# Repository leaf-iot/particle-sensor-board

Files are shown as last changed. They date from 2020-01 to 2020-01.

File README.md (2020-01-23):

# particle-sensor-board
Particle / Feather based sensor interface board

Interface for Particle Boron/Argon/Xenon and other Feather compliant boards.

Features:
- Input voltage and current monitoring via INA226
- On-board microSD card slot for data logging
- On-board BME280 Sensor for Temp / Humidity / Barometric Pressure
- Two Atlas Scientific EZO sensor interfaces with full isolation
- Two 4-20mA current loop interfaces
- 3.3V, GND, A0, A1, D8 pins exposed on screw terminal block
- DC input is 3.5x1.1mm (meant for Voltaic Systems solar panels)
- Enable / Disable EZO and 4-20mA power via I/O pins from Feather device
- TTL Serial pins exposed via separate 4-pin header

Known Issues:
- There is a bug in the microSD card circuit, the MISO and MOSI lines were reversed accidentally during development. Due to this, software SPI needs to be used with the pins configured this way.
- No on-board battery charging circuit. We relied on the Particle Boron's built in BQ24195 chip for charging, however up to this point we have had nothing but issues with this. There have been several hardware and firmware issues identified by the community with the Boron (including incorrectly limiting charge current when using the VUSB pin, input current limit settings not being honored, as well as several issues with solar charging in sleep mode). Some of these problems are yet to be fixed as of this release. 
- Particle Boron u-blox modems are capable of connecting to Verizon, but Borons produced after a certain date were never registered with Verizon, and as such you will have nothing but problems with connectivity and FPLMN blacklists if you attempt to use these devices with Verizon or Hologram sim cards. Stick with the internal sim and you should be okay.

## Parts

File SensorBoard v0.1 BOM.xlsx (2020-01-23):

Quantity | Designator | Comment | Description | Footprint | Manufacturer | Manufacturer Part Number | Supplier | Supplier Part Number
10 | C1, C3, C5, C7, C9, C12, C14, C16, C18, C26 | 10uF | Capacitor Non Polar, Ceramic Chip Capacitor | C1206 | Taiyo Yuden | TMK316AB7106KLHT | Digi-Key | 587-3485-1-ND
17 | C2, C4, C6, C8, C10, C11, C13, C15, C17, C19, C20, C24, C25, C27, C28, C29, C30 | 100nF | Capacitor Non Polar, Ceramic Chip Capacitor | C0805 | Samsung | CL21B104KCFWPNE | Digi-Key | 1276-6733-1-ND
1 | C21 | 470pF | Capacitor Non Polar | C0805 | Samsung | CL21B471KC6WPNC | Digi-Key | 1276-6597-1-ND
1 | C22 | 4.7uF | Capacitor Non Polar | C1206 | Murata | GCJ31CR71E475KA12L | Digi-Key | 490-5808-1-ND
1 | C23 | 470uF | Capacitor Polar | CAPAE120103X102N | Panasonic | EEEHC1C471P | Digi-Key | PCE3751CT-ND
1 | D1 | Diode_Schottky | Diode Schottky 40V 1A SOD-123F | SOD-123F | ON Semiconductor / Fairchild | SS14FL | Digi-Key | SS14FLCT-ND
1 | D2 | Diode_Schottky | DIODE SCHOTTKY 40V 3A SMA | SMA (DO-214AC) | Diodes | B340A-13-F | Digi-Key | B340A-FDICT-ND
1 | J1 | 4-20mA_IN1 | Terminal Block 2 position | TB-2P-5.08mm | Phoenix Contact | 1729128 | Digi-Key | 277-1247-ND
1 | J2 | 4-20mA_IN2 | Terminal Block 2 position | TB-2P-5.08mm | Phoenix Contact | 1729128 | Digi-Key | 277-1247-ND
4 | J5, J6, J7, J8 | HDR 1X3 | HEADER 1X3 | TH,POS-3S,RCPTCL, 2.54mm | Sullins | PPPC031LFBN-RC | Digi-Key | S7036-ND
1 | J9 | SENSOR1 | Terminal Block 2 position | TB-2P-5.08mm | Phoenix Contact | 1729128 | Digi-Key | 277-1247-ND
1 | J10 | SENSOR2 | Terminal Block 2 position | TB-2P-5.08mm | Phoenix Contact | 1729128 | Digi-Key | 277-1247-ND
1 | J12 | IO | Terminal Block 5 position | TB-5P-5.08mm | Phoenix Contact | 1729157 | Digi-Key | 277-1250-ND
1 | J14 | JST-2P | JST 2 Pin, Shrouded Connector | JST-2P TH V/T 2.0mm | JST | B2B-PH-K-S(LF)(SN) | Digi-Key | 455-1704-ND
1 | J16 | SOLAR IN | DC Barrel Jack Connector Male | PWR_JACK_1.1x3.5mm | Wurth Electronics | 694103303002 | Digi-Key | 732-5925-ND
1 | J17 | MicroSD | MicroSD Connector | MicroSD_H-10 | Hirose | DM3CS-SF | Digi-Key | HR1972CT-ND
1 | L1 | 10uH | Generic Inductor | INDP5050X40L | Taiyo Yuden | NR5040T100M | Digi-Key | 587-2365-1-ND
1 | M1 | Particle | Particle BORON Module | Particle Module | Particle | BORON | Particle | *
2 | Q1, Q2 | 2N7002 | N-Channel Power MOSFET with Diode | SOT23 | ON Semiconductor | 2N7002KT1G | Digi-Key | 2N7002KT1GOSCT-ND
5 | R1, R2, R7, R8, R18 | 1MR | Generic Resistor | R0805 | Yageo | AC0805FR-071ML | Digi-Key | YAG3704CT-ND
12 | R3, R4, R5, R6, R20, R21, R22, R23, R28, R29, R31, R34 | 4.7kR | Generic Resistor | R0805 | Yageo | AC0805FR-074K7L | Digi-Key | YAG3738CT-ND
2 | R9, R10 | 4.99R | Generic Resistor | R0805 | Yageo | RC0805FR-074R99L | Digi-Key | 311-4.99CRCT-ND
3 | R11, R19, R38 | 84.5kR | Generic Resistor | R0805 | Vishay | CRCW080584K5FKEA | Digi-Key | 541-84.5KCCT-ND
6 | R12, R13, R14, R15, R16, R17 | 1.5kR | Generic Resistor | R0805 | Yageo | AC0805FR-071K5L | Digi-Key | YAG3701CT-ND
0 | R24 | 0R | DO NOT POPULATE | R0805 | * | * | * | *
6 | R25, R26, R27, R35, R36, R37 | 10kR | Generic Resistor | R0805 | Yageo | AC0805FR-0710KL | Digi-Key | 311-10KLGCT-ND
1 | R30 | 80mR | Generic Resistor | R2512 | Bourns | CRA2512-FZ-R080ELF | Digi-Key | CRA2512-FZ-R080ELFCT-ND
2 | R32, R33 | 10R | Generic Resistor | R0805 | Yageo | AC0805FR-0710RL | Digi-Key | YAG3690CT-ND
1 | S1 | DEBUG | Slide Switch DPDT | * | ITT C&K | JS202011CQN | Digi-Key | 401-2001-ND
2 | U1, U2 | ADM3260ARSZ | ANALOG DEVICES ADM3260ARSZ Digital Isolator, 2 Channel, 3 V, 5.5 V, SSOP, 20 Pins | SSOP-20 | Analog Devices | ADM3260ARSZ | Digi-Key | ADM3260ARSZ-ND
2 | U3, U4 | INA196AIDBVR | IC CURRENT MONITOR 3% SOT23-5 | SOT23-5 | Texas Instruments | INA196AIDBVR | Digi-Key | 296-26068-1-ND
1 | U5 | MIC2250-2YD5TR | Conv DC-DC Single Step Up 2.5V to 5.5V 5-Pin TSOT-23 T/R | SOT23-5 | Microchip Micrel | MIC2250-2YD5TR | Digi-Key | 576-3968-1-ND
1 | U6 | ADS1115IDGSR | IC ADC 16BIT 860SPS LP 10MSOP | VSSOP-10 | Texas Instruments | ADS1115IDGSR | Digi-Key | 296-38849-1-ND
1 | U7 | SN74AHC126D | IC BUS BUFFER TRI-ST QD 14SOIC | SOIC-14 | Texas Instruments | SN74AHC126D | Digi-Key | 296-26392-5-ND
1 | U8 | INA226AQDGSRQ1 | IC MONITOR PWR/CURR BIDIR 10MSOP | MSOP-10 | Texas Instruments | INA226AQDGSRQ1 | Digi-Key | 296-42503-1-ND
1 | U9 | BME280 | PRESSURE HUMIDITY TEMP GAS SENS | LGA-8 -1 | Bosch Sensortec | BME280 | Digi-Key | 828-1063-1-ND
95

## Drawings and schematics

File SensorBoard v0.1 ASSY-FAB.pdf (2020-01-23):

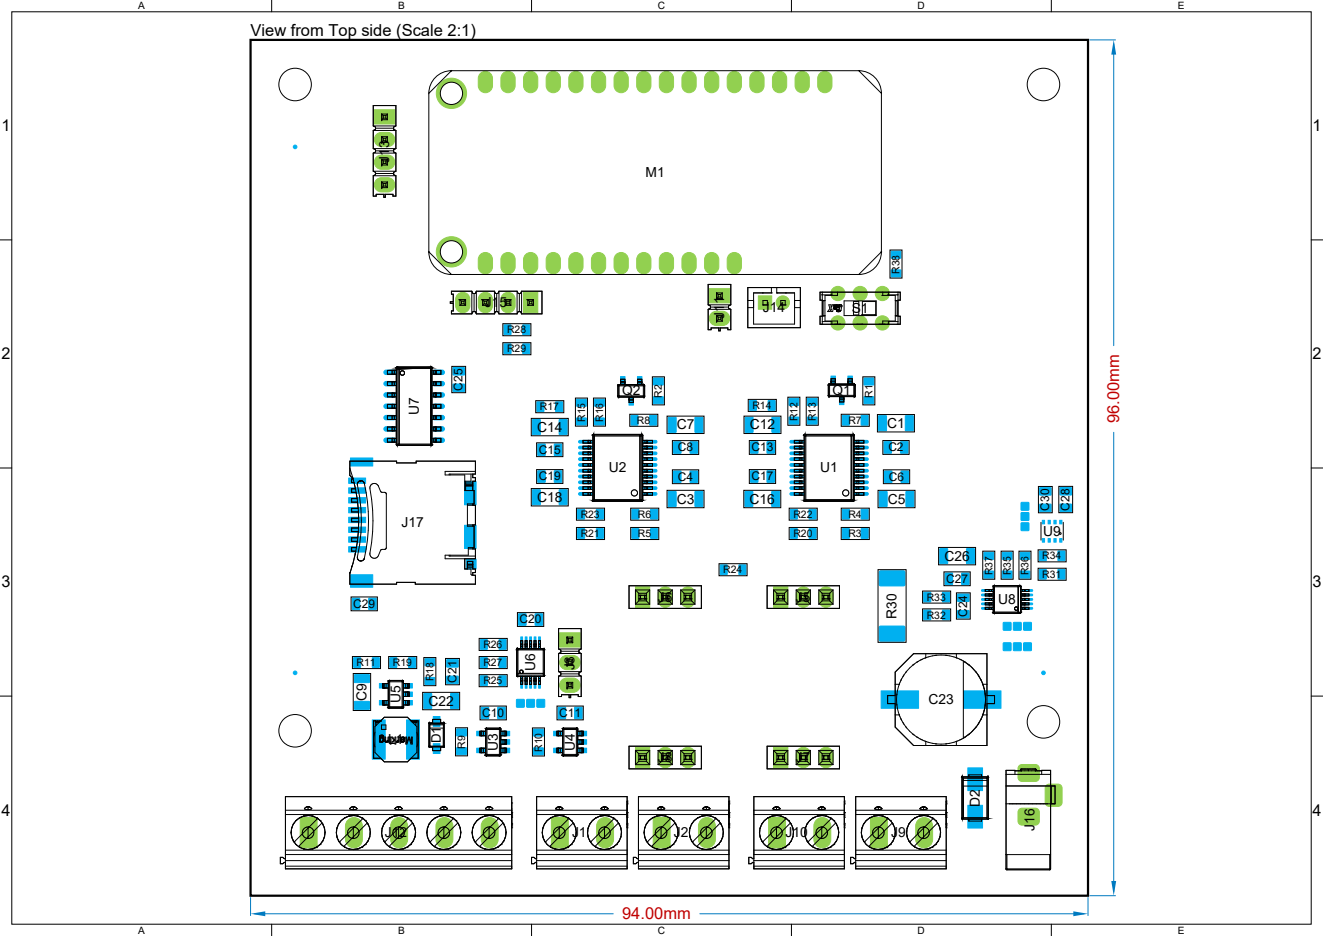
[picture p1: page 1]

View from Top side (Scale 2:1)

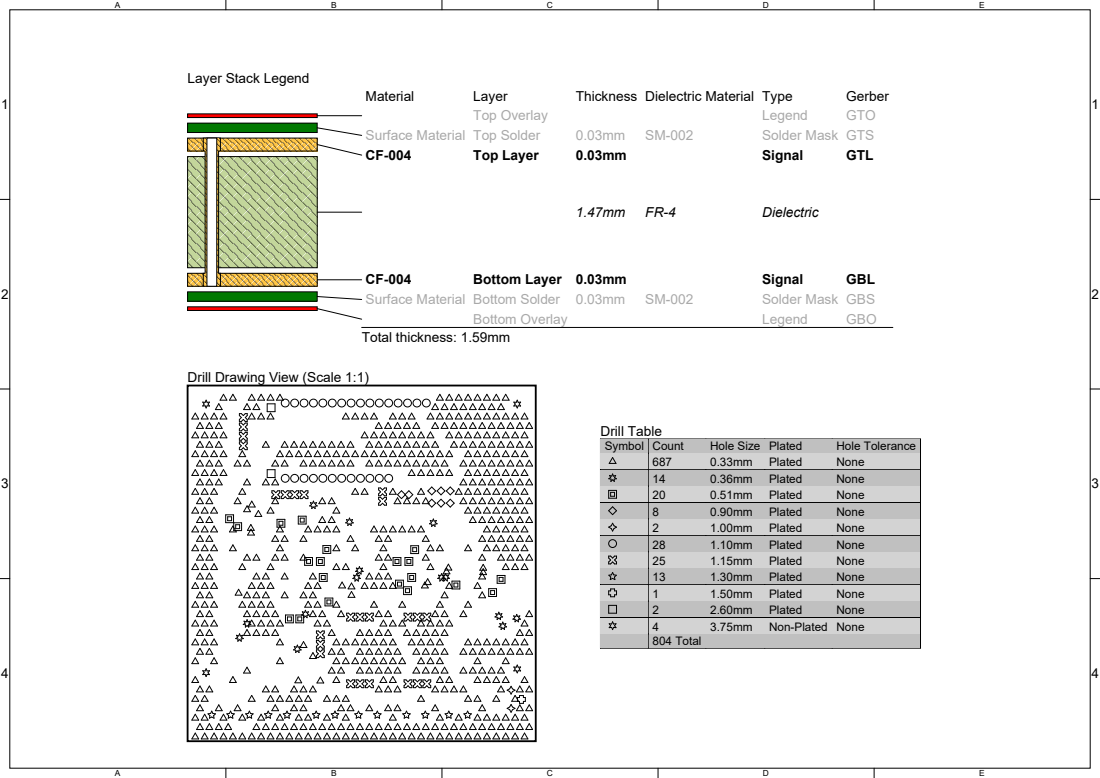
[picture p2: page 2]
Drill Table; Material; Layer; Thickness Dielectric Material Type; Gerber; Top Overlay; Legend; GTO; Surface Material Top Solder; Solder Mask GTS; Top Layer; Signal; GTL; Dielectric; Bottom Layer 0.03mm; GBL; Surface Material Bottom Solder 0.03mm; Solder Mask GBS; Bottom Overlay; GBO; Total thickness: 1.59mm

Layer Stack Legend

Drill Drawing View (Scale 1:1)

Symbol | Count | Hole Size | Plated | Hole Tolerance

687 | 0.33mm | Plated | None
14 | 0.36mm | Plated | None
20 | 0.51mm | Plated | None
8 | 0.90mm | Plated | None
2 | 1.00mm | Plated | None
28 | 1.10mm | Plated | None
25 | 1.15mm | Plated | None
13 | 1.30mm | Plated | None
1 | 1.50mm | Plated | None
2 | 2.60mm | Plated | None
4 | 3.75mm | Non-Plated | None
804 Total

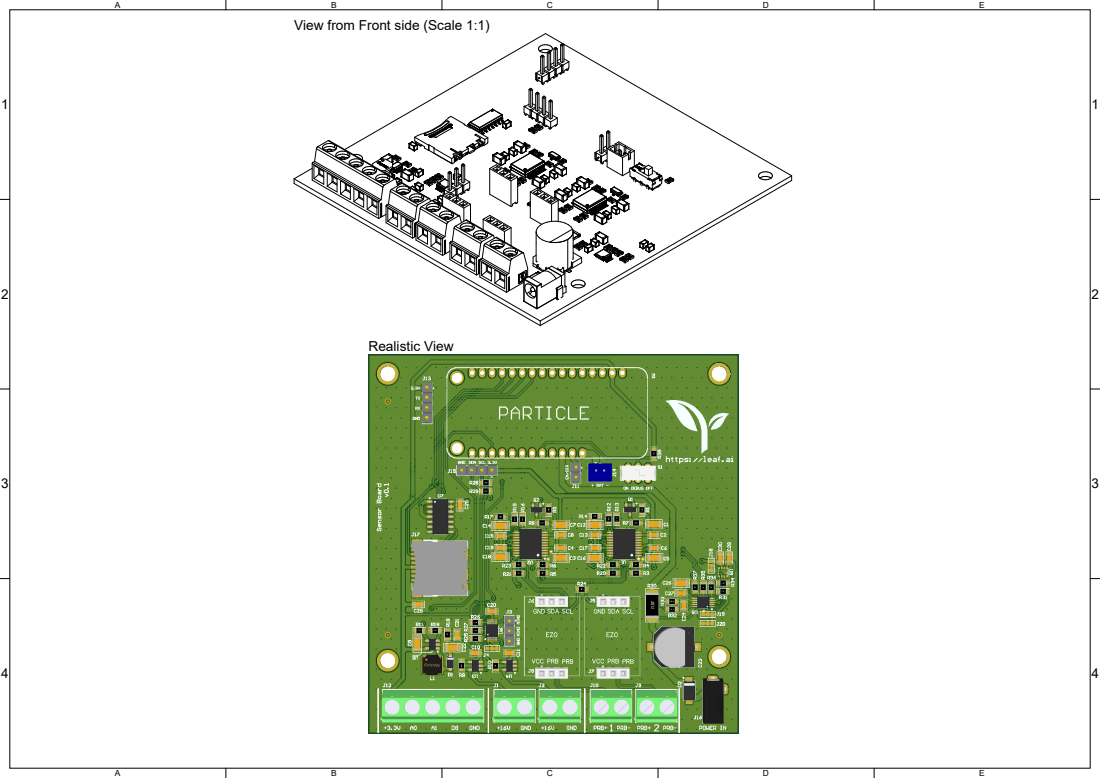
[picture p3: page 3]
Realistic View

View from Front side (Scale 1:1)

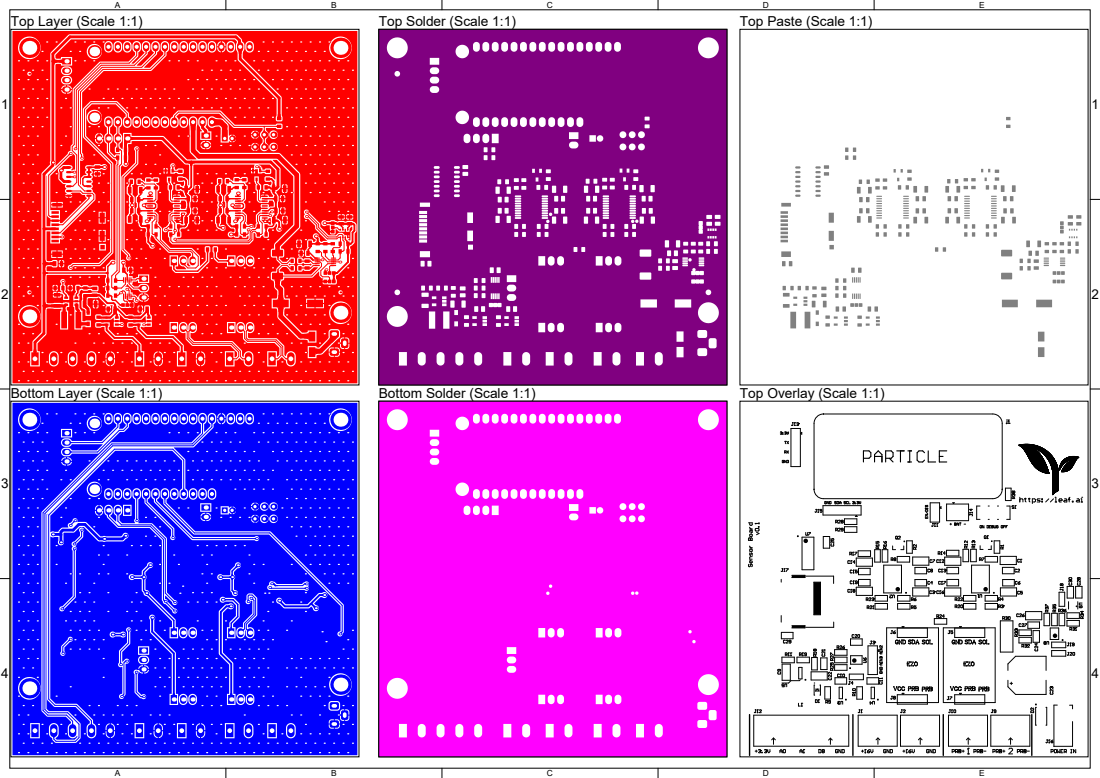
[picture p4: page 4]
Top Layer (Scale 1:1); Top Solder (Scale 1:1); Top Paste (Scale 1:1); Bottom Layer (Scale 1:1); Bottom Solder (Scale 1:1); Top Overlay (Scale 1:1)

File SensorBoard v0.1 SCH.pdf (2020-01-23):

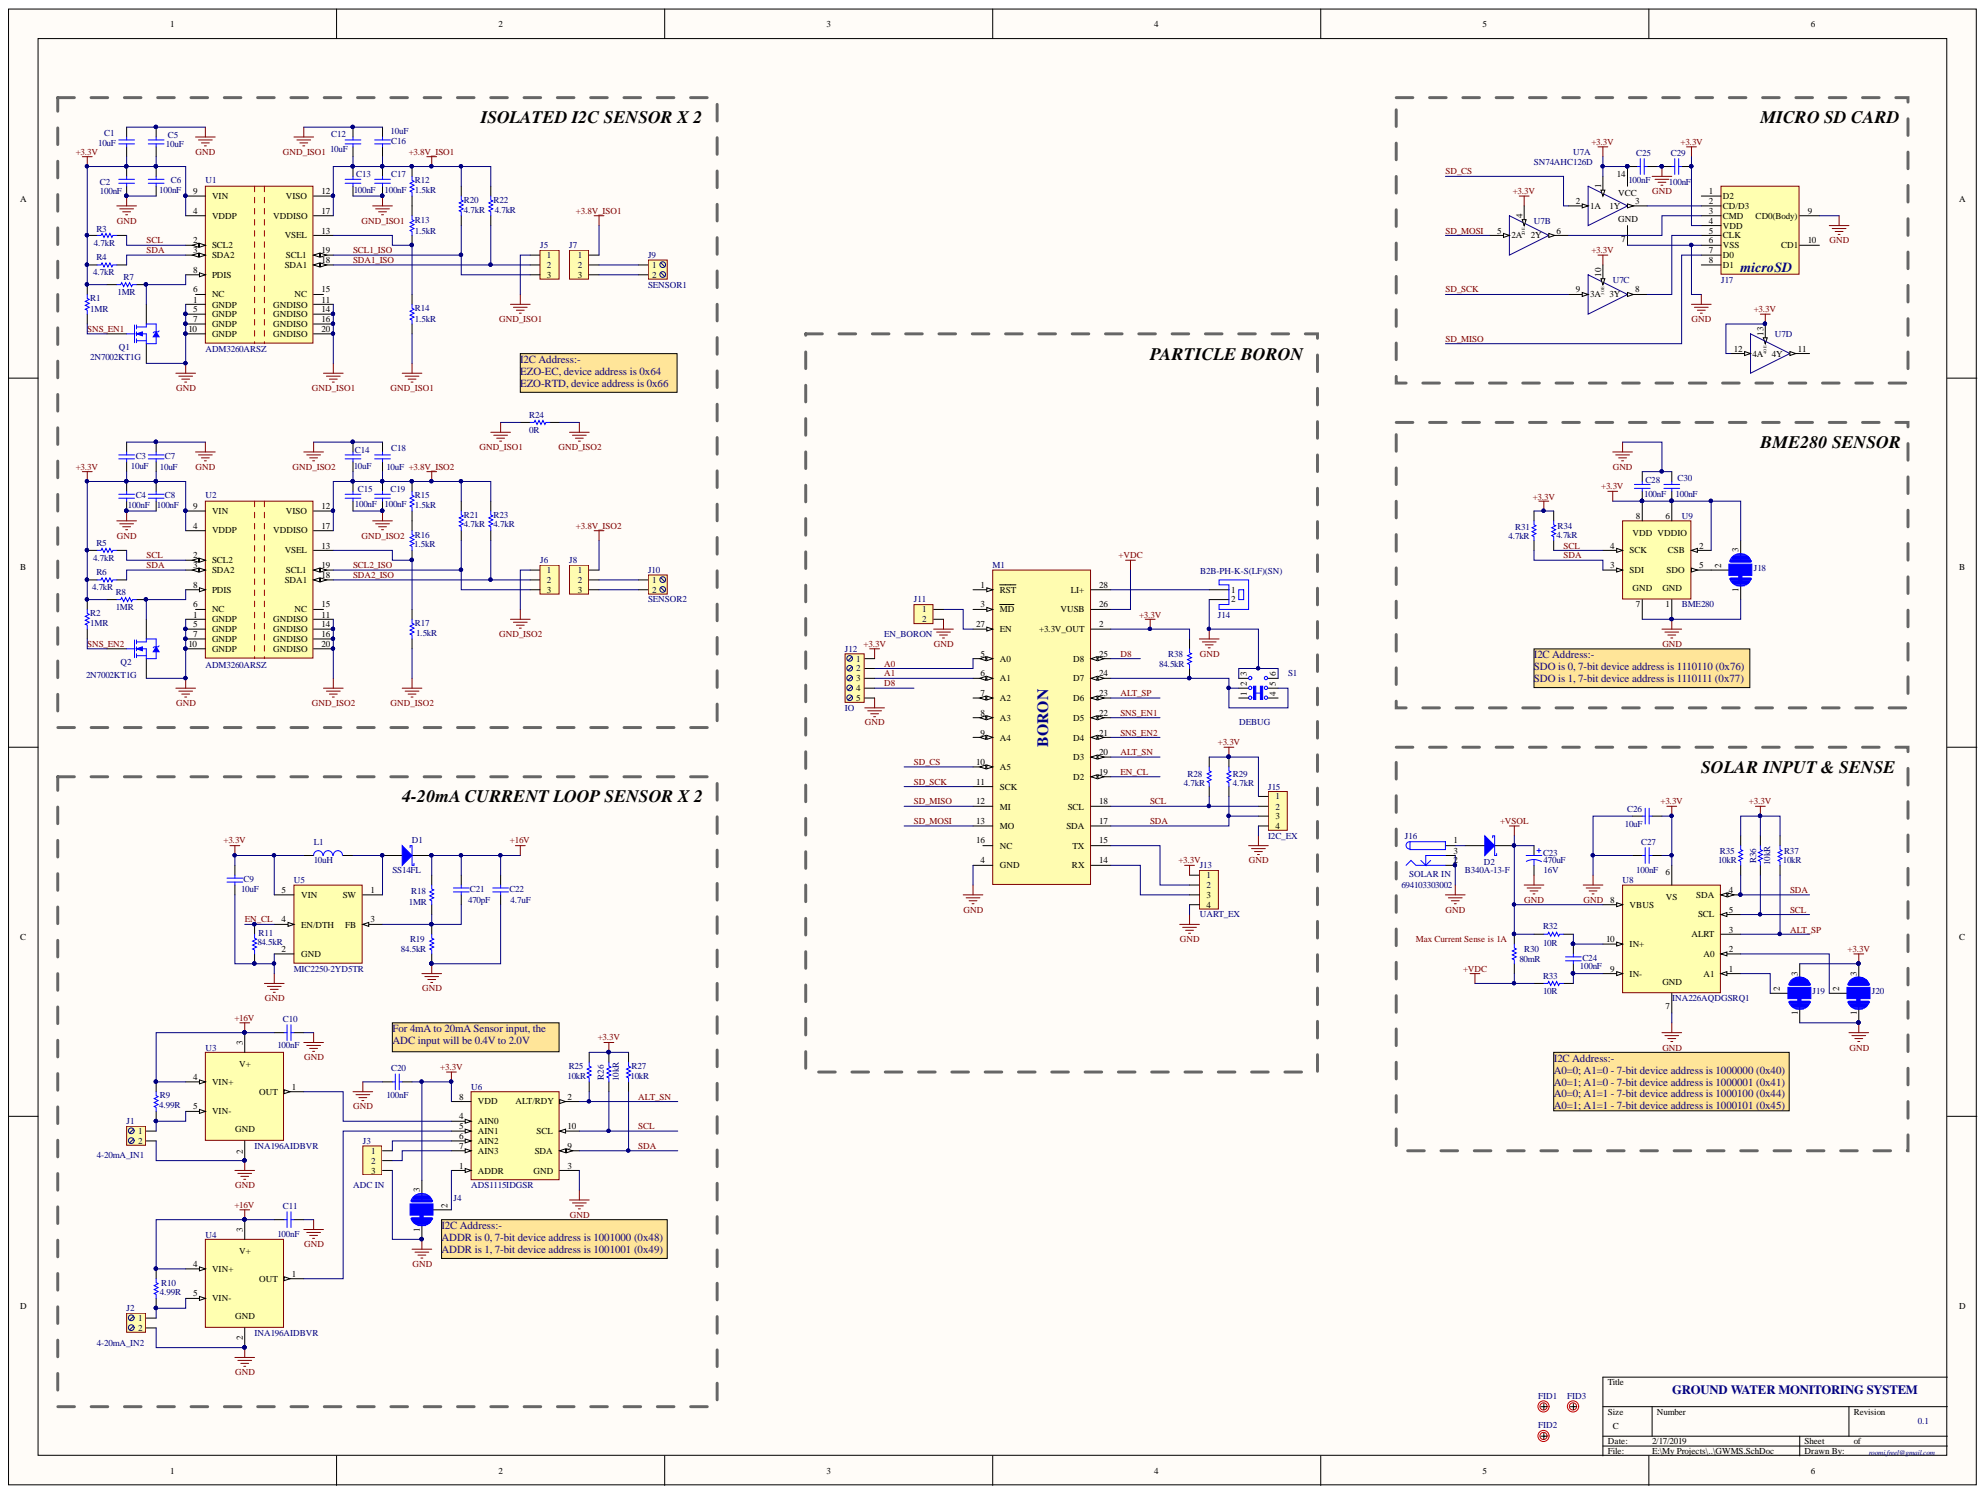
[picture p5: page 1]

I2C Address:-
EZO-EC, device address is 0x64
EZO-RTD, device address is 0x66

SDO is 0, 7-bit device address is

SDO is 1, 7-bit device address is

For 4mA to 20mA Sensor input, the
ADC input will be 0.4V to 2.0V

A0=0; A1=0 - 7-bit device address is 1000000 (0x40)
A0=1; A1=0 - 7-bit device address is 1000001 (0x41)
A0=0; A1=1 - 7-bit device address is 1000100 (0x44)

A0=1; A1=1 - 7-bit device address is 1000101 (0x45)

ADDR is 0, 7-bit device address is 1001000 (0x48)
ADDR is 1, 7-bit device address is 1001001 (0x49)
